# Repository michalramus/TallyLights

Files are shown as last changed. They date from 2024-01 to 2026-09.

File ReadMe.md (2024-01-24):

# Tally Lights by Michal Ramus

## Table of contents

* [General info](#general-info)
* [Features](#features)
* [Parts list](#parts-list)
* [How to assemble](#how-to-assemble)
* [Installation](#installation)
* [Configuration](#configuration)
* [TallyArbiter configuration](#tallyarbiter-configuration)
* [WiFi reconfiguration](#wifi-reconfiguration)
* [Led status](#led-status)
* [OTA update](#ota-update)
* [TODO](#todo)

## General info

Cheap tally lights which support [TSL 3.1 and 5.0 protocol.](tsl-umd-protocol.pdf) Software can be replaced by any other which works on WeMos D1 Mini. For example [vTally.](https://github.com/wifi-tally/wifi-tally)

Tally light

## Features

* Based on WeMos D1 Mini
* Compatible with [TallyArbiter](https://github.com/josephdadams/TallyArbiter)
* Overall cost is about 35 EUR
* Support TSL 3.1 and 5.0 protocol
* Powered by 18650 battery
* WiFi connection
* Easy to modify

## Parts list

| Part | Quantity |
| :--- | :---: |
| WeMos D1 mini | 1 |
| TP4056 charging module | 1 |
| 18650 battery | 1 |
| 18650 battery holder | 1 |
| 5050WS2812B LED | 12 |
| 2 position switch SS12F15 | 1 |
| 0.1 uF capacitor | 12 |
| R0603 10k resistor | 1 |
| R0603 20k resistor | 1 |
| tactile button 6x6x6mm | 1 |
| JST-XH-2Pin connector | 1 |
| JST-XH-3Pin connector | 2 |
| M2x3mm screw | 1 |
| M3x4mm screw | 2 |
| M3x6mm screw | 7 |
| 3D printed parts |
| PCB|
| Some wires |

## How to assemble

### Pinout

| Pin | Description |
| :---| :--- |
| A0 | Battery voltage |
| D1 | WS2812B Leds (first connected back leds) |
| D2 | Button (needs to be pulled up) |

### Assembly

> ***Before soldering [flash firmware](#installation) into WeMos D1 mini.*** After soldering, it will be hard because of usb port location.

1. Solder all SMD components
2. Solder all THT components
    > **Important:** From the bottom side of PCB, none of the pins should be extended. This side should be as flat as possible.
    >
    > Leave space between WeMos D1 mini and PCB. Solder TP4056 as close as possible to PCB.
    >
    > Don't solder JST-XH connector on the led matrix.

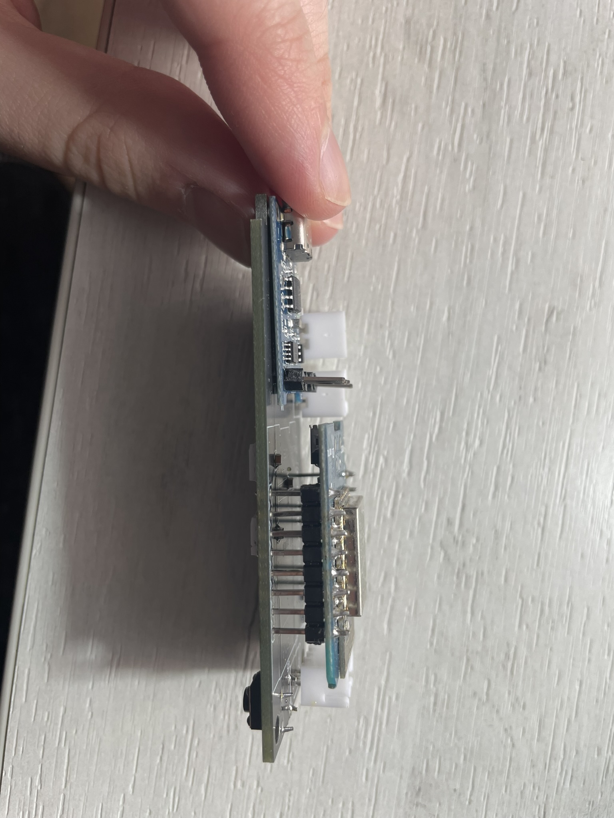
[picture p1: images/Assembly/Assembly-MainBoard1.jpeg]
Main board1
    
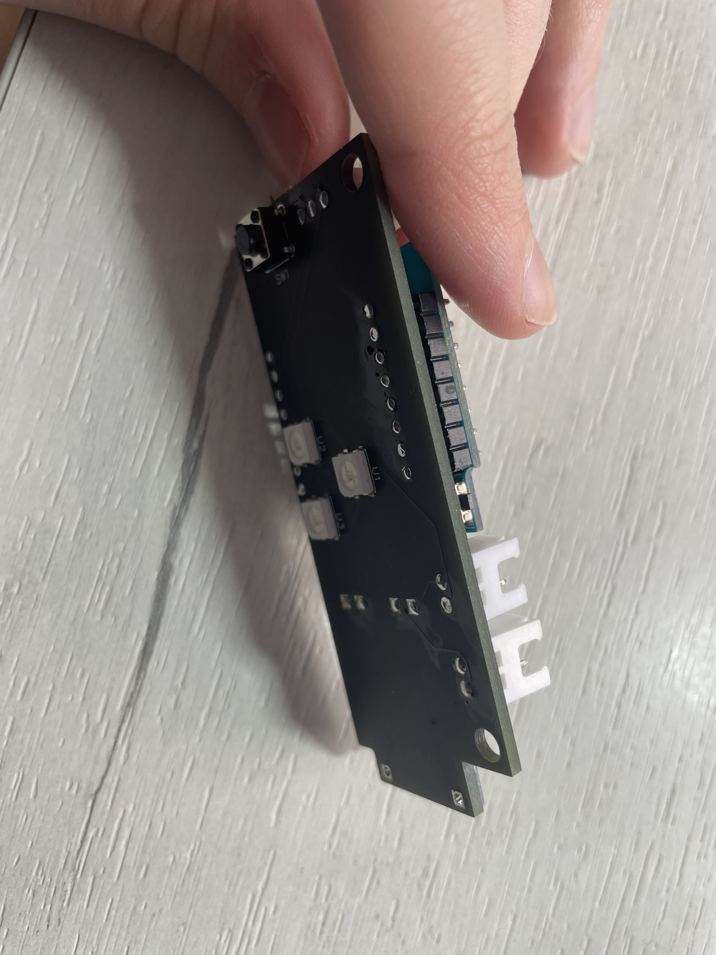
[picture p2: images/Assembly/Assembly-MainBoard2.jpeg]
Main board2
    

3. Solder wires directly to the led matrix (length around 4 cm)
4. Screw Led matrix to the cover using M3x4mm screws (Led matrix is symmetrical, check if you are screwing it in the right direction)

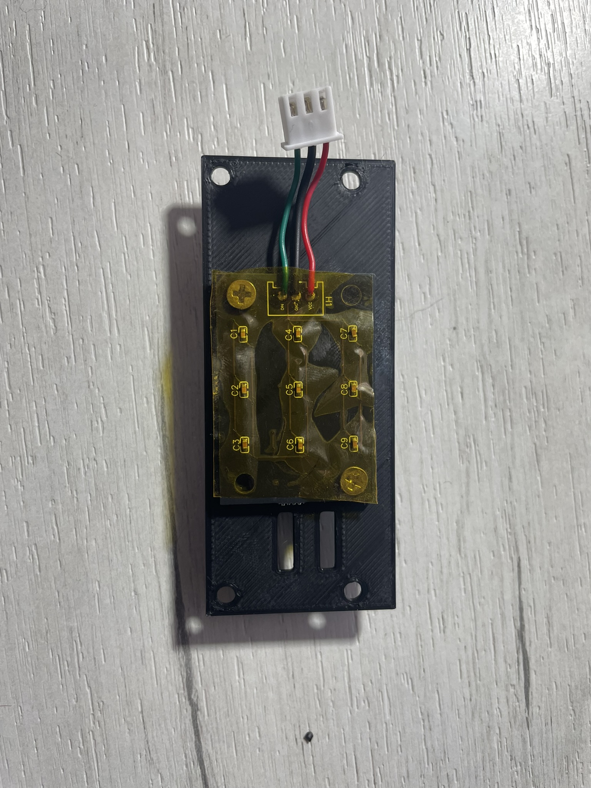
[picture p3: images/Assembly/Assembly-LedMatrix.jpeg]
Led matrix
    

5. Solder wires to switch (length around 8 cm)
6. Screw main board to the main case by M3x6mm screws
7. Glue 18650 battery holder to the bottom part
    * If you are going to use longer battery(e.g. EverActive 18650 which is 69mm long), you can cut in half the battery holder and glue it maximally to the sides.

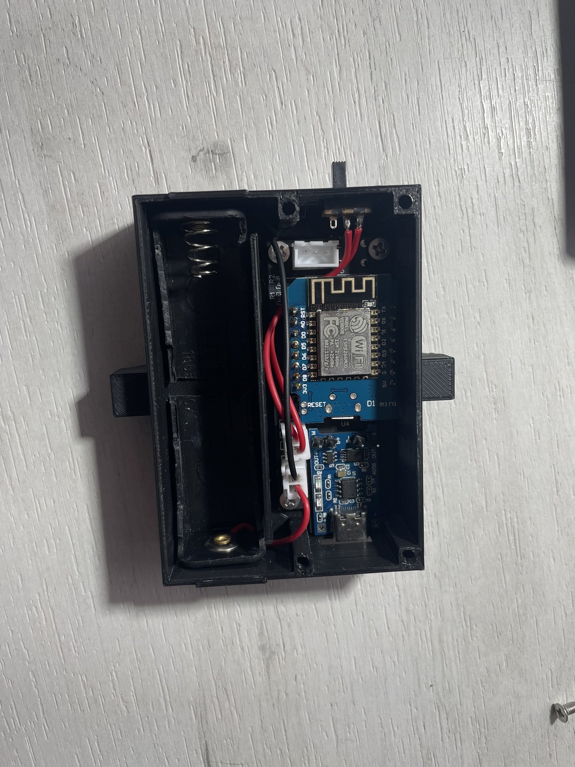
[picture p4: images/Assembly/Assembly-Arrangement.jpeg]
Main board screwed
    

8. Screw switch to the cover using M2x3mm screw
9. Crimp all JST-XH plug connectors to the wires (check polarity)
10. Connect all wires to the main board
11. Screw cover to the main board using M3x6mm screws
12. Glue casings

## Installation

Download Visual Studio Code and install PlatformIO extension. Open project and compile it. Connect WeMos D1 Mini to PC and upload firmware.

After first boot, device will create WiFi network with name `TallyLight-MAR-<MacAddress>`. Connect to it and type `192.168.4.1` in browser. You will see configuration page. Enter SSID and password of your WiFi network and click `Save`. Device will reboot and connect to your WiFi network. Next you have to set [TSL address.](#configuration)

## Configuration

Tally uses udp packages to communicate on port 10373.

To establish connection with device type `netcat -u <ipAddress> 10373` into terminal.

| Command | Description |
| :--- | :--- |
| `CONF+BAT` | Get battery voltage |
| `CONF+GetTSLAddress` | Get TSL address. May be overestimated or underestimated by approximately 0.2V|
| `CONF+SetTSLAddress+<address>` | Set TSL address. Address must be in range 0-255 |
| `CONF+OTAMode` | Enter into OTA mode. OTA password is `TallyMAR_OTA` |

## TallyArbiter configuration

### TSL 3.1

> **NOTE:**  TallyArbiter doesn't allow to make modifications in tally behavior(change brightness etc.) [Last significant bit enables preview light. Second last significant bit enables live light.](TallyLight-Firmware/src/PackageManager/PackageParser/PackageParserTSL3_1.cpp)

1. Enter into `Listeners` tab
2. Add TSL client
    * `IP Address` - tally light ip address
    * `Port` - 10373
    * `Transport` - UDP

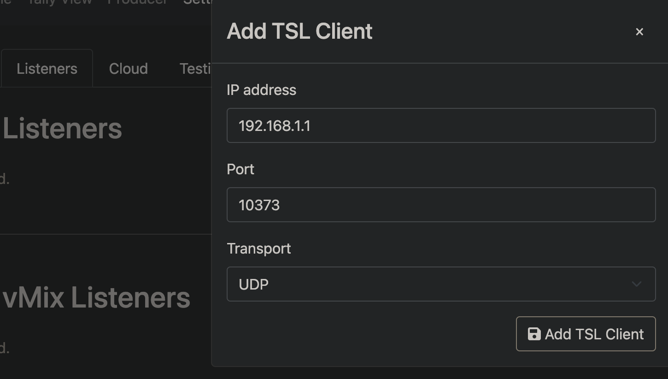
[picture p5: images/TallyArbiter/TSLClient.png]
TSL Client
    

3. Enter into `Sources & Devices` tab
4. Add Device
    * `TSL Address` - tally light TSL address

### TSL 5.0

> **NOTE:** TallyArbiter doesn't support TSL 5.0 protocol as source. It is possible to use it with `Device Actions`. Because of modus operandi of `Device Actions`, it is strongly recommended to use only live light, otherwise current state may be overwritten by other `Device Action` - they are not called in order.

1. Enter into `Sources & Devices` tab
2. Add Device
    * `TSL Address` - tally light TSL address
3. Enter into `Edit Actions` tab
4. Add `Device Action` to turn on live light
    * `Bus` - Program
    * `Active` - On
    * `Output mode` - TSL 5 UDP
    * `IP Address` - tally light ip address
    * `Port` - 10373
    * `Address Index` - TSL address
    * `Screen` - leave as it is
    * `Label` - leave as it is
    * `Text Tally` - Red or Off(if you want to disable front light)
    * `Right Tally` - Red
    * `Left Tally` - Off leave as it is
    * `Brightness` - set according to your needs
    * `DLE/STX` - leave as it is

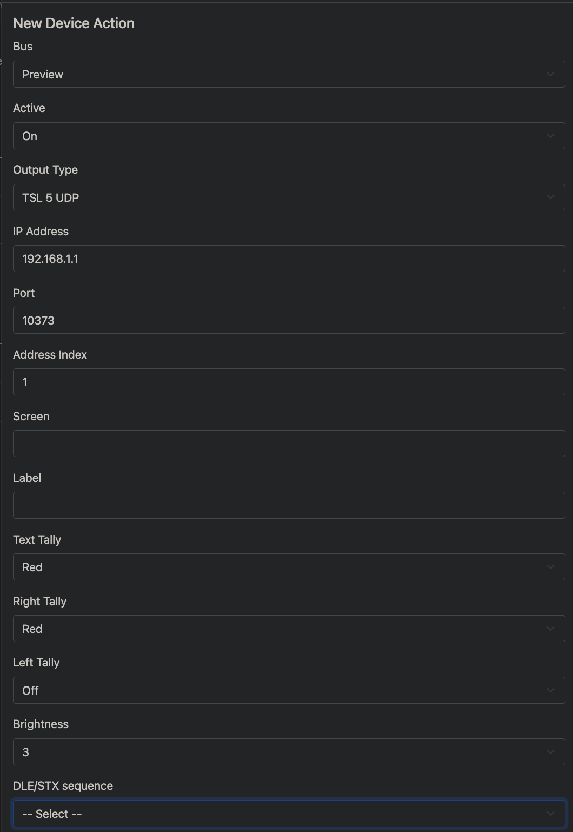
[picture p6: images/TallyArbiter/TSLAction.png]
TSL 5.0 Device Action
    
5. Analogically add `Device Action` to turn off live light
    * `Active` - Off
    * `Text Tally` - Off
    * `Right Tally` - Off

## WiFi reconfiguration

When device disconnects from WiFi network, it will be trying to reconnect. To change WiFi network, press and hold button and turn on device. Device will create WiFi network with name `TallyLight-MAR-<MacAddress>`. Connect to it and use configuration page to change WiFi network.

## Led status

| Color | Description |
| :--- | :--- |
| #40ccff Blue | Trying to connect to WiFi |
| #bf40ff Purple | Device in OTA mode or WiFi reconfiguration mode |

## OTA update

To change firmware over WiFi enter into [OTA mode.](#configuration) OTA password is `TallyMAR_OTA`. After that you can use Arduino IDE or PlatformIO to upload new firmware.

## TODO

- [ ] Write script to control tally lights instead of TallyArbiter
- [ ] Correct lid latch - the latch quickly becomes loose

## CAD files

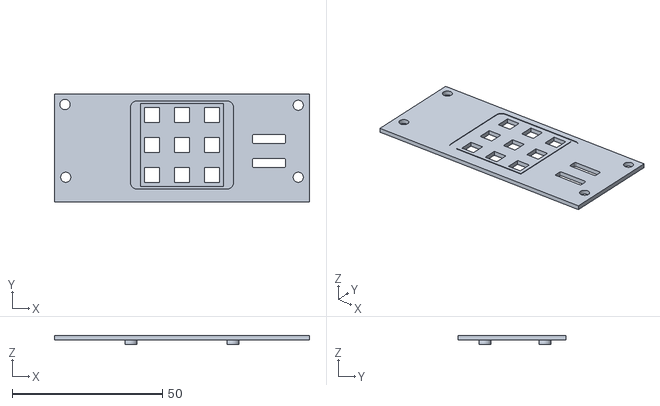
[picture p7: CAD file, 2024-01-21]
CAD/Stl/Led matrix cover.stl
85.0 x 36.0 x 3.00

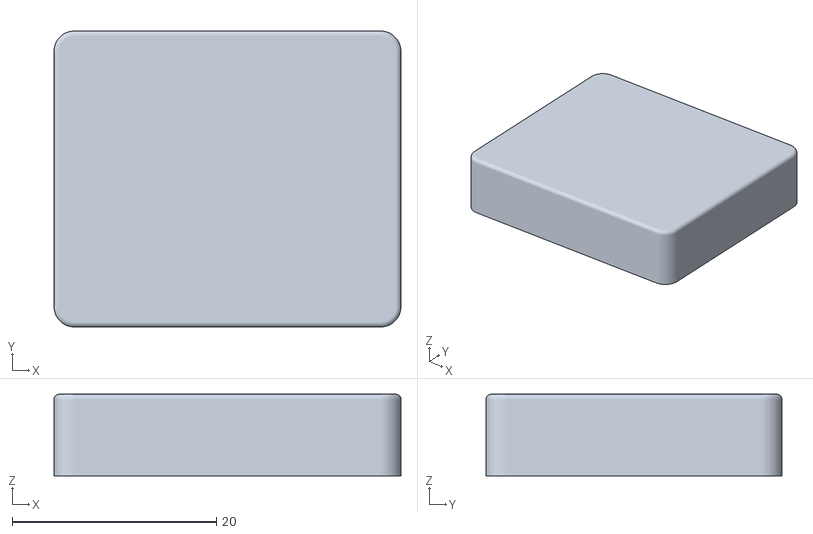
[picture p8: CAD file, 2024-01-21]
CAD/Stl/Print using transparent filament/Front casing.stl
34.0 x 29.0 x 8.00

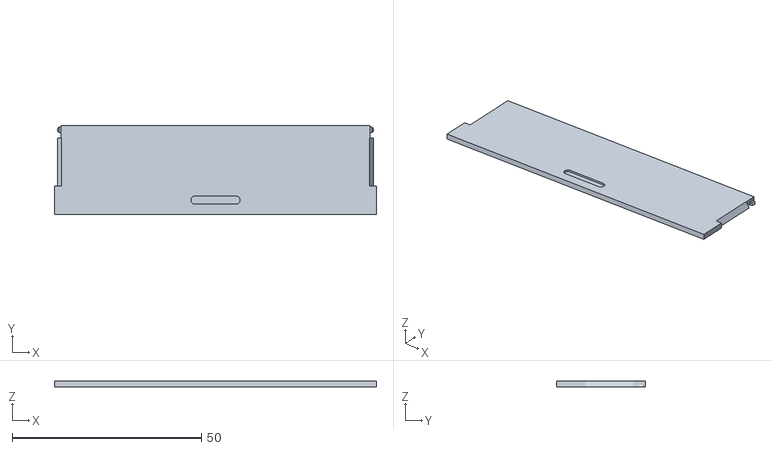
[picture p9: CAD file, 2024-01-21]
CAD/Stl/Lid.stl
85.0 x 23.5 x 1.50

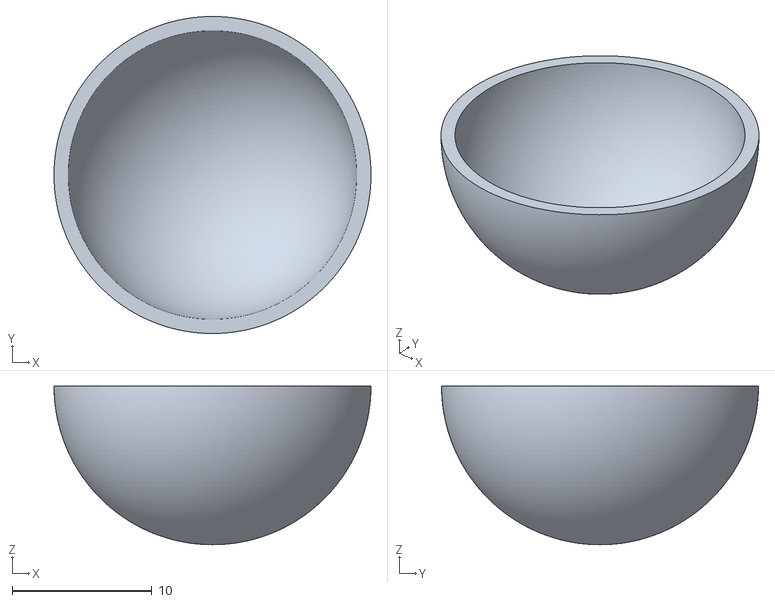
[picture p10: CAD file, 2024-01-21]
CAD/Stl/Print using transparent filament/Back casing.stl
22.7 x 22.7 x 11.3

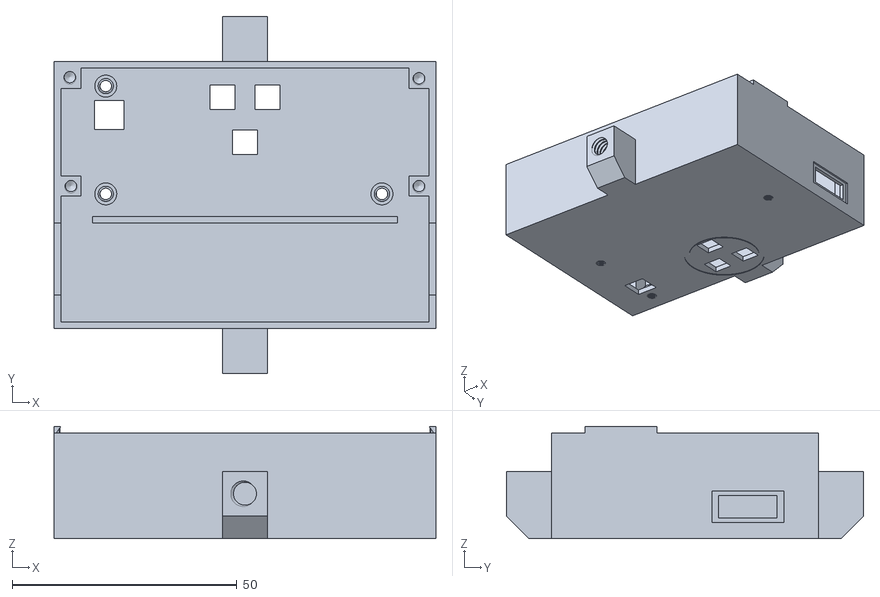
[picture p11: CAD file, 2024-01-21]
CAD/Stl/base.stl
85.0 x 79.5 x 25.0

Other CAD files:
CAD/Tally Light Michal Ramus.f3d

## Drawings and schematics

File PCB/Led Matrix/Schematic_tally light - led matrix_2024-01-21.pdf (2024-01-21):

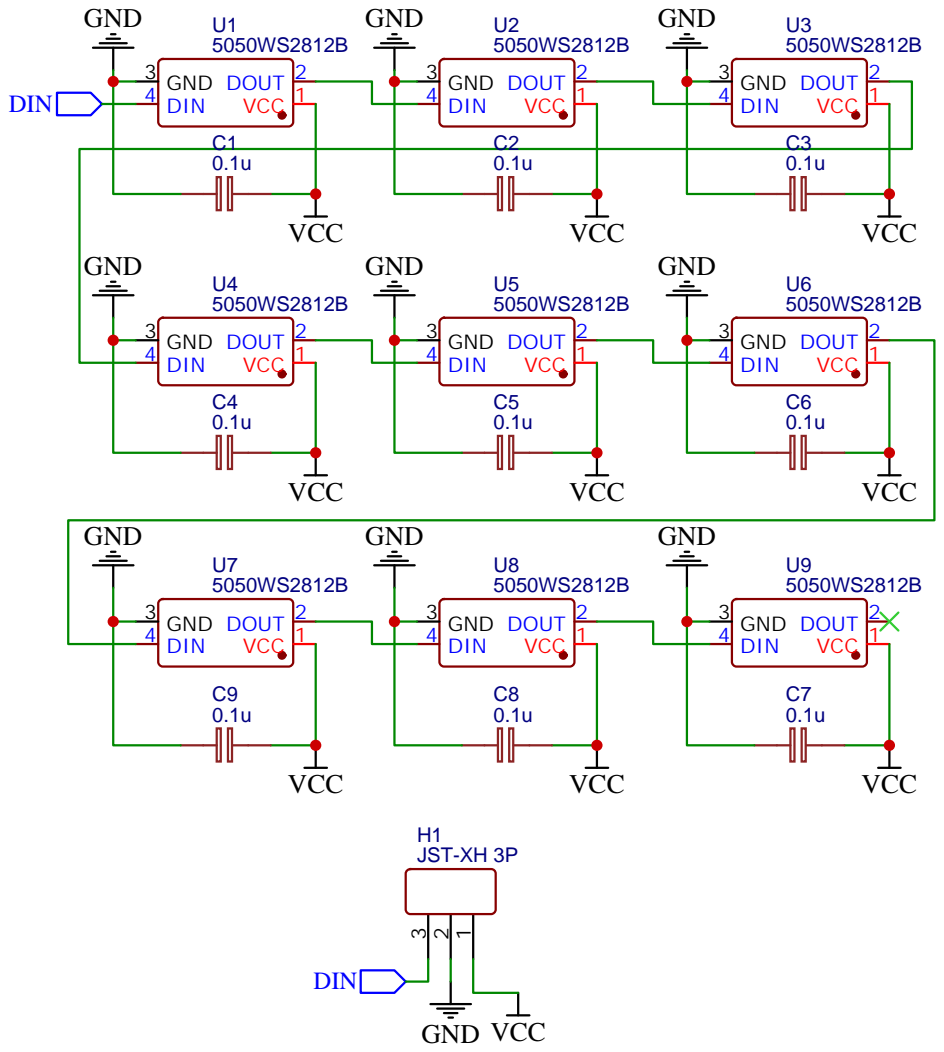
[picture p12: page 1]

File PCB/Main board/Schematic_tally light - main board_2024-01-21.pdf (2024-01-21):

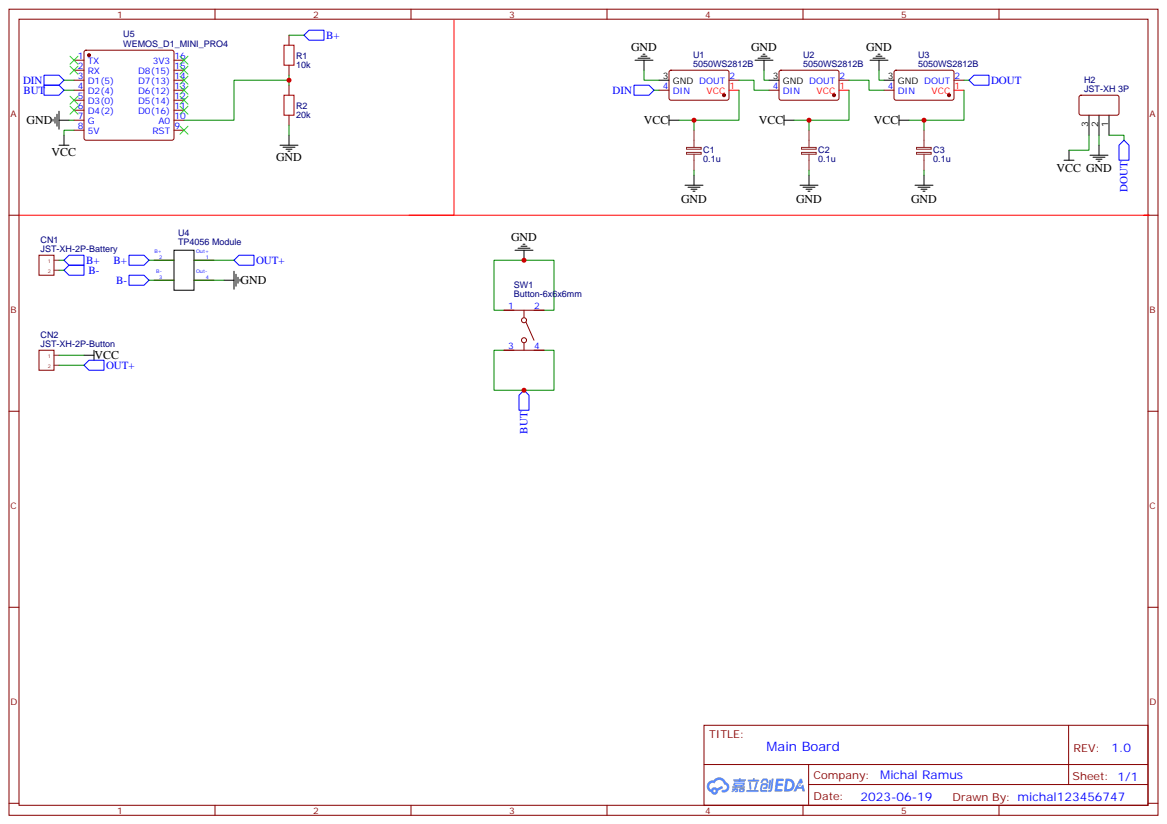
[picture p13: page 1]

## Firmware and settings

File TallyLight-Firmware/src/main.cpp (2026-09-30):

#include "BatteryReader/BatteryReader.hpp"

#include "LedDriver/LedDriver.hpp"

#include "LittleFS/LittleFSManager.hpp"
#include "LittleFS/LittleFSFileList.hpp"

#include "PackageManager/PackageExecutor/PackageExecutor.hpp"
#include "PackageManager/PackageExecutor/PackageExecutorConfigPackages.hpp"
#include "PackageManager/PackageParser/PackageParserTSL3_1.hpp"
#include "PackageManager/PackageParser/PackageParserTSL5_0.hpp"
#include "PackageManager/PackageTypeResolver.hpp"

#include <Arduino.h>
#include <ArduinoOTA.h>
#include <DNSServer.h>
#include <ESP8266WebServer.h>
#include <ESP8266WiFi.h>
#include <ESP8266mDNS.h>
#include <FastLED.h>
#include <WiFiManager.h>
#include <WiFiUdp.h>

// AP access data
String AP_SSID = "TallyLight-MAR-" + WiFi.macAddress();
const char *AP_PASS = "TallyMAR";

// leds
#define LEDS_PIN D1
#define NUM_LEDS 12
CRGB ledsArray[NUM_LEDS];

#define BUTTON_PIN D2

// udp
WiFiUDP udp;
uint16_t udpPort = 10373;
const uint16_t udpPacketMaxSize = 512;
uint8_t udpPacketBuffer[udpPacketMaxSize];
uint16_t udpPacketSize = 0;

void setup()
{
    Serial.begin(76800);

    // leds initialization
    FastLED.addLeds<WS2812B, LEDS_PIN, GRB>(ledsArray, NUM_LEDS);
    LedDriver_init(ledsArray, LedSegmentAddresses(3, 11, 0, 2));
    Serial.println("Leds initialized");

    // button initialization
    pinMode(BUTTON_PIN, INPUT_PULLUP);
    Serial.println("Button initialized");

    // battery reader initialization
    BatteryReader_init(A0, 5.0, 0.0);

    // LittleFS initialization
    if (!LittleFSManager_init())
    {
        Serial.println("Critical error. Restarting...");
        LedDriver_setMode(LedDriver_LedModes::live);
        delay(1000);
        ESP.restart();
    }

    LedDriver_setMode(LedDriver_LedModes::preview);
    delay(1000);

    // wifi initialization
    if (digitalRead(BUTTON_PIN) == LOW)
    {
        // initialize wifi in AP mode
        Serial.println("WiFi AP mode");
        LedDriver_setMode(LedDriver_LedModes::configMode);

        WiFiManager wifiManager;
        wifiManager.startConfigPortal(AP_SSID.c_str(), AP_PASS);
    }
    else
    {
        // initialize wifi in STA mode
        Serial.println("WiFi STA mode");
        LedDriver_setMode(LedDriver_LedModes::wifiNotConnected);

        WiFi.begin();
        WiFi.setSleepMode(WIFI_NONE_SLEEP);
        Serial.print("Connecting to WiFi");
        while (WiFi.status() != WL_CONNECTED)
        {
            Serial.print('.');
            delay(500);
        }
        Serial.println("");
    }


    LedDriver_setMode(LedDriver_LedModes::preview); // if mode change is not doubled, not working
    LedDriver_setMode(LedDriver_LedModes::preview);
    Serial.println("WiFi connected");

    delay(500);
    LedDriver_setMode(LedDriver_LedModes::off); // if mode change is not doubled, not working
    LedDriver_setMode(LedDriver_LedModes::off);

    // initialize udp
    udp.begin(udpPort);
    Serial.println("UDP initialized");

    // initialize PackageExecutor
    uint16_t tslAddress = 0;
    uint8_t tslAddressBuffer[2];
    if (LittleFSManager_readFileContent(LittleFS_FileList.tslAddressFile, tslAddressBuffer, 2) != -1)
    {
        tslAddress = (tslAddressBuffer[0] << 8) | tslAddressBuffer[1];
        PackageExecutor_SetTslAddress(tslAddress);
        Serial.println("TSL address: " + String(tslAddress));
    }
    else
    {
        Serial.println("TSL address not found, using default: 0");
        PackageExecutor_SetTslAddress(0);
        LedDriver_setMode(LedDriver_LedModes::contentLaterUse); // if mode change is not doubled, not working
        LedDriver_setMode(LedDriver_LedModes::contentLaterUse);
        delay(500);
    }

    LedDriver_setMode(LedDriver_LedModes::off); // if mode change is not doubled, not working
    LedDriver_setMode(LedDriver_LedModes::off);
}

void loop()
{
    // check wifi connection
    if (WiFi.status() != WL_CONNECTED)
    {
        Serial.println("Wifi not connected");
        LedDriver_setMode(LedDriver_LedModes::wifiNotConnected);
        LedDriver_setBrightness(255, LedDriver_LedSegments::back);

        while (WiFi.status() != WL_CONNECTED)
        {
            Serial.print('.');
            WiFi.reconnect();
            delay(5000);
        }
        Serial.println("\nWifi connected");

        LedDriver_setMode(LedDriver_LedModes::off); // if mode change is not doubled, not working
        LedDriver_setMode(LedDriver_LedModes::off);
    }


    // UDP
    udpPacketSize = udp.parsePacket();
    if (udpPacketSize)
    {
        udpPacketSize = udp.read(udpPacketBuffer, udpPacketMaxSize);
        Serial.println("UDP packet received");

        Package package;
        String udpResponse;
        switch (PackageManager_ResolvePackageType(udpPacketBuffer, udpPacketSize))
        {
            case PackageManager_PackageTypes::tsl3_1:
                package = PackageManager_ParsePackageTSL3_1(udpPacketBuffer);
                PackageExecutor_Execute(package);

                break;

            case PackageManager_PackageTypes::tsl5_0:
                package = PackageManager_ParsePackageTSL5_0(udpPacketBuffer, udpPacketSize);
                PackageExecutor_Execute(package);

                break;
            case PackageManager_PackageTypes::config:

                udpResponse = PackageExecutor_ExecuteConfigPackage((char *)udpPacketBuffer);

                if (udpResponse != "")
                {
                    udpResponse += "\n";
                    udp.beginPacket(udp.remoteIP(), udp.remotePort());
                    udp.write(udpResponse.c_str());
                    udp.endPacket();
                }
                break;

            default:
                break;
        }

        udpPacketSize = 0; // reset packets
    }
}

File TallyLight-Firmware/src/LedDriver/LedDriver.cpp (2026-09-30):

/**
 * @file LedDriver.cpp
 * @brief Implementation of the LedDriver module
 */

#include "LedDriver/LedDriver.hpp"

#include "LedDriver/LedColors.hpp"
#include "LedDriver/LedEnumerates.hpp"
#include "LedDriver/LedSegment.hpp"
#include "LedDriver/LedSegmentAddresses.hpp"

#include <FastLED.h>

//---------------------------- variables ----------------------------
CRGB *leds = nullptr;

LedSegment frontSegment = LedSegment();
LedSegment backSegment = LedSegment();

//---------------------------- functions prototypes ----------------------------
void LedDriver_updateSegment(LedSegment frontSegment, LedSegment backSegment);

//---------------------------- functions ----------------------------

void LedDriver_init(CRGB *leds, LedSegmentAddresses config)
{
    ::leds = leds;

    frontSegment.beginIndex = config.frontBeginIndex;
    frontSegment.endIndex = config.frontEndIndex;
    backSegment.beginIndex = config.backBeginIndex;
    backSegment.endIndex = config.backEndIndex;

    LedDriver_setMode(LedDriver_LedModes::off);
    Serial.println("LedDriver initialized");
}

void LedDriver_setMode(LedDriver_LedModes mode)
{
    switch (mode)
    {
        case LedDriver_LedModes::off:
            frontSegment.color = LedDriver_offColor;
            backSegment.color = LedDriver_offColor;
            LedDriver_updateSegment(frontSegment, backSegment);
            Serial.println("LedMode: off");
            break;

        case LedDriver_LedModes::preview:
            frontSegment.color = LedDriver_previewColor;
            backSegment.color = LedDriver_previewColor;
            LedDriver_updateSegment(frontSegment, backSegment);
            Serial.println("LedMode: preview");
            break;

        case LedDriver_LedModes::live:
            frontSegment.color = LedDriver_liveColor;
            backSegment.color = LedDriver_liveColor;
            LedDriver_updateSegment(frontSegment, backSegment);
            Serial.println("LedMode: live");
            break;

        case LedDriver_LedModes::contentLaterUse:
            frontSegment.color = LedDriver_contentLaterUseColor;
            backSegment.color = LedDriver_contentLaterUseColor;
            LedDriver_updateSegment(frontSegment, backSegment);
            Serial.println("LedMode: contentLaterUse");
            break;

        case LedDriver_LedModes::wifiNotConnected:
            frontSegment.color = LedDriver_wifiNotConnectedColor;
            backSegment.color = LedDriver_wifiNotConnectedColor;
            LedDriver_updateSegment(frontSegment, backSegment);
            Serial.println("LedMode: wifiNotConnected");
            break;

        case LedDriver_LedModes::configMode:
            frontSegment.color = LedDriver_configModeColor;
            backSegment.color = LedDriver_configModeColor;
            LedDriver_updateSegment(frontSegment, backSegment);
            Serial.println("LedMode: configMode");
            break;


        default:
            break;
    }
}

void LedDriver_setBrightness(uint8_t brightness, LedDriver_LedSegments segment)
{
    switch (segment)
    {
        case LedDriver_LedSegments::front:
            frontSegment.brightness = brightness;
            LedDriver_updateSegment(frontSegment, backSegment);
            Serial.println("LedBrightness: front - " + String(brightness));
            break;
            
        case LedDriver_LedSegments::back:
            backSegment.brightness = brightness;
            LedDriver_updateSegment(frontSegment, backSegment);
            Serial.println("LedBrightness: back - " + String(brightness));
            break;

        default:
            break;
    }
}

//---------------------------- private functions ----------------------------

void LedDriver_updateSegment(LedSegment frontSegment, LedSegment backSegment)
{
    for (uint16_t i = frontSegment.beginIndex; i <= frontSegment.endIndex; i++)
    {
        leds[i] = frontSegment.color;
        leds[i].subtractFromRGB(255 - frontSegment.brightness);
    }

    for (uint16_t i = backSegment.beginIndex; i <= backSegment.endIndex; i++)
    {
        leds[i] = backSegment.color;
        leds[i].subtractFromRGB(255 - backSegment.brightness);
    }

    FastLED.show();
}

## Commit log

2023-12-03 feat: Create LedDriver module
2023-12-03 feat: Add more led colors
    Add colors:
    1. wifiNotConnected - blue
    2. configMode - purple
    3. contentLaterUse - amber
2023-12-03 ref: Move predefined led brightness values from PackageManager to LedDriver
2023-12-03 feat: Change enabled segment in config and wifiNotConnected led modes
    Enabled segment should be backSegment instead of front. Only operator
    needs to know if tally is not connected to wifi
2023-12-03 feat: Create BatteryReader module
    Module reads battery voltage
2023-12-03 bug: Add log when received package is shorter than 2 bytes
    [PackageTypeResolver.cpp]
2024-01-21 Add CAD and PCB files
    [Back casing.stl, Front casing.stl, Led matrix cover.stl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]
2026-09-30 fix: Disable wifi sleep mode
    When wifi sleep mode enabled, tallys update their lights with huge
    latency between 1s and 10s
    [LedDriver.cpp, main.cpp]
